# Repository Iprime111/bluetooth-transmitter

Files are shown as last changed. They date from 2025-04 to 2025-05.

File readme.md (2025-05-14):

# Bluetooth Audio Transmitter  
  
  


Портативный Bluetooth-передатчик для беспроводной передачи звука с аналоговых источников (3.5 мм) на наушники или колонки.  
**Цель проекта**: Интеграция проводных аудиоустройств в современные беспроводные экосистемы.

---

## 🚀 Особенности
- **Bluetooth A2DP**: Передача стереозвука с поддержкой кодеков SBC.
- **OLED-дисплей**: SSD1306 (32x64 пикселей) для управления и отображения:
  - Список доступных для подключения устройств.
  - Уровень громкости.
- **Энкодер EC11**: Интуитивное управление (выбор устройств, регулировка громкости).
- **Компактный дизайн**: Корпус 93x61x33 мм, напечатанный на 3D-принтере (PLA).
- **Автономность**: Работа от Li-Po аккумулятора 1050 мАч с зарядкой через USB-C.
- **Открытый исходный код**: Полная документация и файлы для самостоятельной сборки.

---

## 🔧 Технологии и компоненты
### Аппаратная часть
| Компонент | Характеристики | Ссылка на Datasheet |
|---|---|---|
| Микроконтроллер | ESP32-WROOM-32 (Bluetooth 4.2 + Wi-Fi)  | [ESP32-WROOM-32](./docs/esp32-wroom-32_datasheet_en.pdf) |
| АЦП | PCM1808 (24-bit, 96 kHz, SNR 112 dB) | [PCM1808](./docs/pcm1808.pdf)  |
| Драйвер дисплея | SSD1306 (I2C) | [SSD1306](./docs/SSD1306.pdf) |
| Стабилизатор питания | ADP3338 (3.3V) / L78L05 (5V) | [ADP3338](./docs/ADP3338.pdf), [L78L05](./docs/l78l-1.pdf) |
| Модуль заряда | IP2326 (USB-C) | [IP2326](./docs/ip2326.pdf) |
| Энкодер | EC11 | [EC11](./docs/PEC11R.pdf) |

### Программная часть
- **Прошивка**: Написана на C с использованием ESP-IDF v4.4.
- **Библиотеки**:
  - `esp_a2dp` — Реализация Bluetooth A2DP Source (встроенная).
  - `i2s_audio` — Захват аудио с АЦП через I2S (встроенная).
  - `ssd1306` — Управление OLED-дисплеем (написана в рамках проекта).
  - `EC11` — Работа с энкодером (написана в рамках проекта).
- **Инструменты**:
  - `KiCad 7.0` — проектирование схемы и PCB.
  - `Autodesk Inventor` — 3D-моделирование корпуса.
  - `ESP-IDF` — сборка и отладка прошивки.

---

## 📦 Сборка устройства
### 1. Аппаратная часть
#### Схемы и PCB
- [Файлы KiCad](https://github.com/Iprime111/bluetooth-transmitter/tree/master/bluetooth-transmitter-pcb):  
  - Принципиальная схема.  
  - Разводка двухсторонней платы.  
  - Gerber-файлы для заказа на производстве.  

#### 3D-модель корпуса
- [STL и IPT-файлы](https://github.com/Iprime111/bluetooth-transmitter/tree/master/case-design):  
  - Корпус состоит из двух частей: верхняя крышка/корпус с отверстиями для дисплея/энкодера, нижняя — крышка на пазовом соединии.  
  - Рекомендуемые параметры печати: слой 0.2 мм, заполнение 15%.

---

### 2. Программная часть
#### Установка зависимостей
1. Установите [ESP-IDF v5.4](https://docs.espressif.com/projects/esp-idf/en/v5.4.1/esp32/get-started/).
2. Клонируйте репозиторий:
   ```bash
   git clone https://github.com/Iprime111/bluetooth-transmitter.git
   cd bluetooth-transmitter
   ```

#### Компиляция и прошивка
1. Подключите ESP32 через USB.
2. Соберите и загрузите проект:
   ```bash
   idf.py build
   idf.py -p /dev/ttyUSB0 flash
   ```

---

## 🎮 Использование
### Основные функции
1. **Подключение источника звука**:  
   Вставьте кабель 3.5 мм в разъем на корпусе.  
2. **Поиск устройств**:  
   - Включите устройство
   - Нажмите на кнопку энкодера для поиска устройств
   - Поворот энкодера → выбор устройства из списка.  
   - Нажмите энкодер для подключения.
   - При необходимости выберите пункт `RESTART DISCOVER` для повторного сканирования 
3. **Управление громкостью и проигрыванием**:  
   - Выберите пункт `PLAY/STOP` для воспроизведения или остановки аудио
   - Войдите в режим изменения громкости путем выбора соответствующего пункта меню. Поворотом энкодера установите желаемый уровень громкости. Для выхода повторно нажмите кнопку энкодера.  
   - Для отключения нажмите кнопку `BACK`.

---

## 📊 Технические характеристики
| Параметр | Значение |
|---|---|
| Радиус действия | До 15 м (в помещении) |
| Автономность | 8 часов (при 50% громкости)  |
| Задержка передачи | < 200 мс |
| Частотный диапазон | 20 Гц – 20 кГц |

---

## 🔄 Сравнение с аналогами
| Параметр | Наш проект | UGREEN Transmitter | Sennheiser BT-T100 |
|---|---|---|---|
| **Стоимость** | ~$20 (DIY) | ~$40 | ~$100 |
| **Размеры** | 93x61x50 мм | 80x50x20 мм | 100x60x25 мм |
| **Открытость** | Полная | Нет | Нет |
| **Кастомизация** | Да (код + корпус) | Нет | Нет |

---

## 📁 Структура репозитория
```
bluetooth-transmitter/
├── components/           # Исходный код прошивки (ESP-IDF)
│   ├── audio-stream/     # Получение звука с PCM1808
│   ├── bluetooth-lib/    # GAP, AVRC, A2DP и управление подключениями
│   ├── dispatcher/       # Вспомогательные функции для асинхронной работы
│   ├── oled-display/     # Драйвер SSD1306
│   ├── main/             # Конфигурация устройства и пользовательский интерфейс
│   └── encoder/          # Обработка энкодера
├── bluetooth-transmitter-pcb/  # Схемы и PCB (KiCad)
├── case-design/          # 3D-модели корпуса (IPT, STL)
├── docs/                 # Документация
└── README.md             # Этот файл
```

---

## 📜 Лицензия
Проект распространяется под лицензией **MIT**.  
Полный текст доступен в файле [LICENSE](LICENSE).

---

## 👥 Команда
- **Владимир Чурсин**  
  - Разработка ПО, 3D-моделирование.  
  - ✉️ `chursin.vv@phystech.edu`  
  - [GitHub](https://github.com/Amlola)  
- **Максим Тимошкин**  
  - Схемотехника, сборка, тестирование.  
  - ✉️ `timoshkin.ma@phystech.edu`  
  - [GitHub](https://github.com/Iprime111)  

---

## 📸 Фото и демонстрация
**Фотография финальной версии устройства**

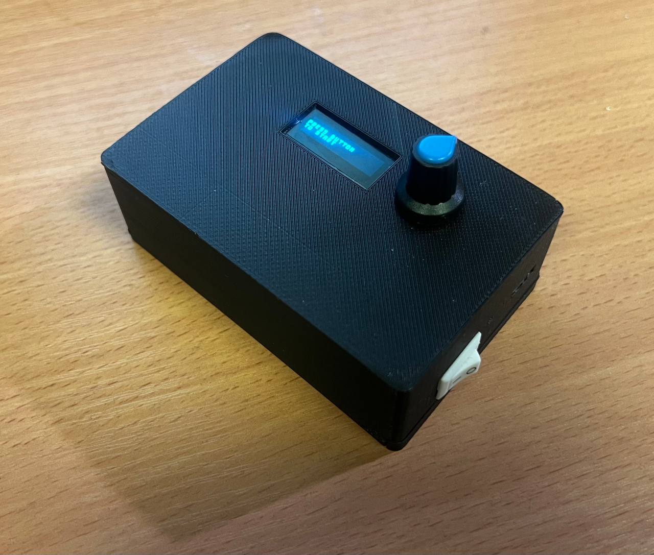
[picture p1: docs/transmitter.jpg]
Bluetooth аудио передатчик


**Фотография прототипа**

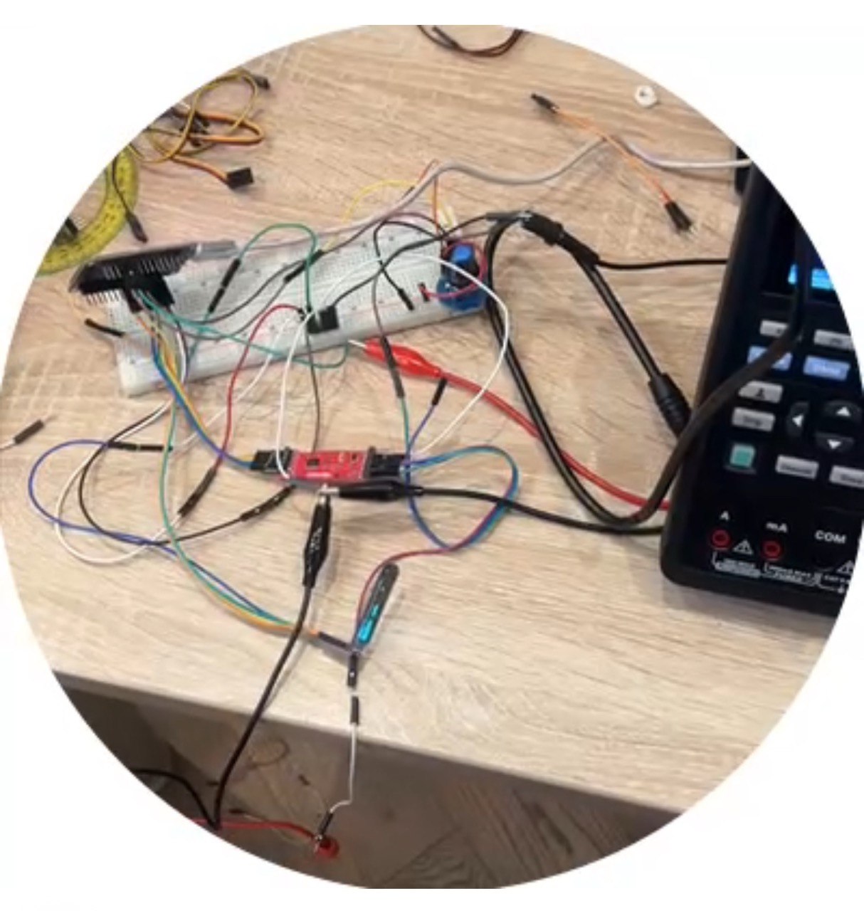
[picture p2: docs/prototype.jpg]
Прототип


**Демонстрация работы**:

<video width="480" height="640" controls>
  <source src="docs/demonstration.mp4" type="video/mp4">
</video>

[Ссылка, если видео не отображается на github](./docs/demonstration.mp4)

---

## 🔮 Будущие улучшения
- Добавление поддержки кодеков aptX.  
- Реализация мультиподключения (2 устройства).  
- Интеграция с мобильным приложением для настройки.  

---

**🔗 Ссылка на проект**: [GitHub](https://github.com/Iprime111/bluetooth-transmitter)

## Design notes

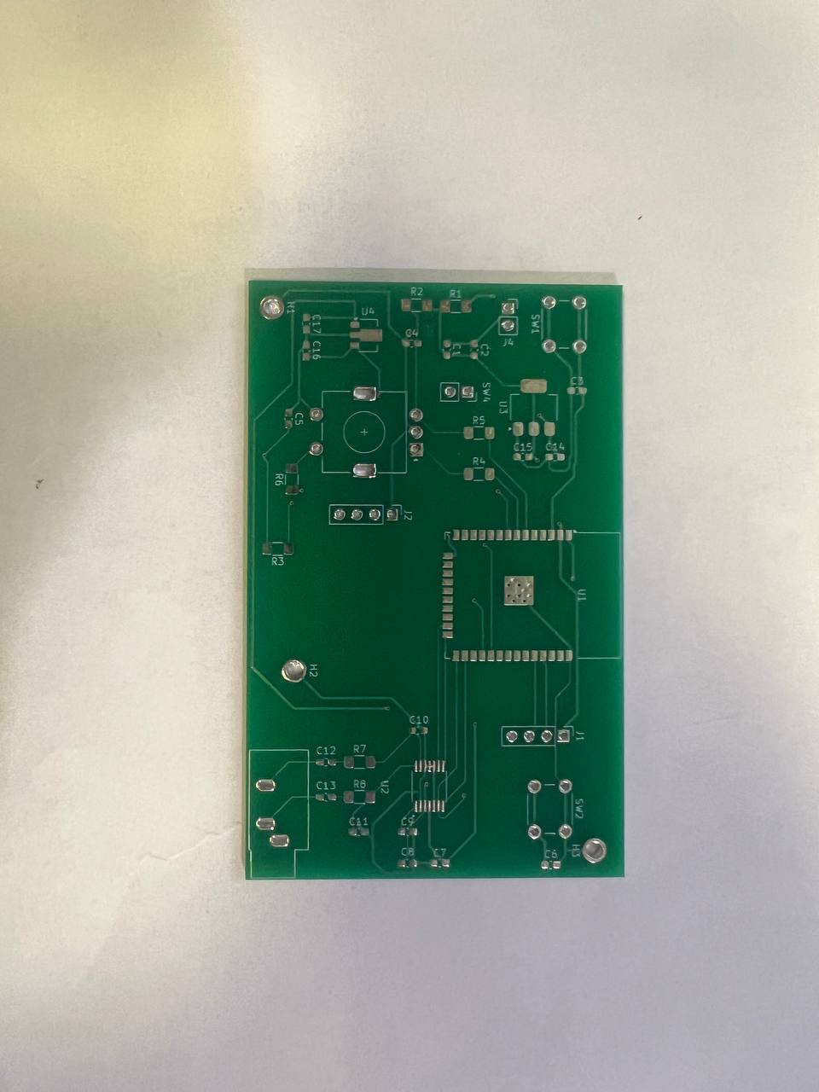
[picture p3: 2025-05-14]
docs/pcb.jpg

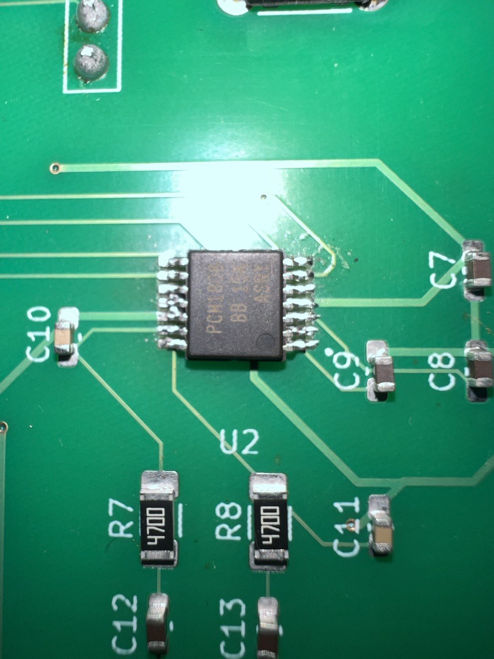
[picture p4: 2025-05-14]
docs/ADC.jpg

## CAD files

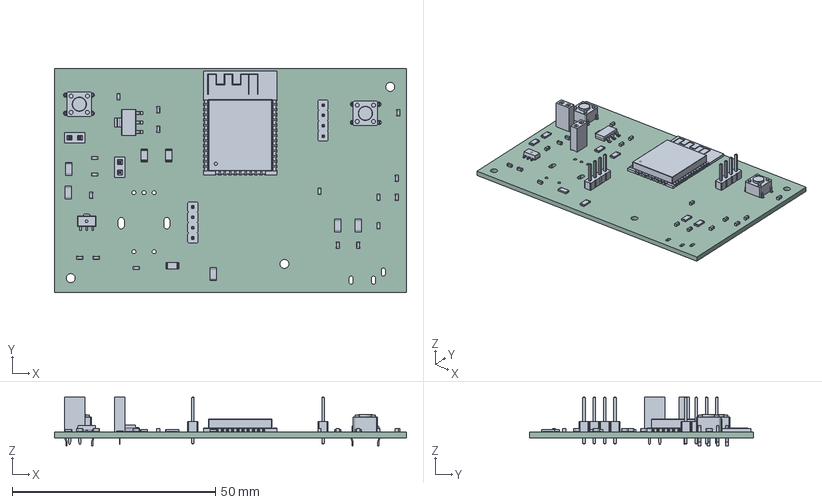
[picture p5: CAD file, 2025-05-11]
bluetooth-transmitter-pcb/bluetooth-transmitter.step
86.5 x 55.0 x 12.0 mm
PinHeader_1x04_P2.54mm_Vertical x 2
C_0603_1608Metric x 17
R_1206_3216Metric x 8
SOT-223
PinSocket_1x02_P2.54mm_Vertical x 2
bluetooth-transmitter 1.22.1
ESP32-WROOM-32
SW_PUSH_6mm_H4.3mm x 2
bluetooth-transmitter_PCB

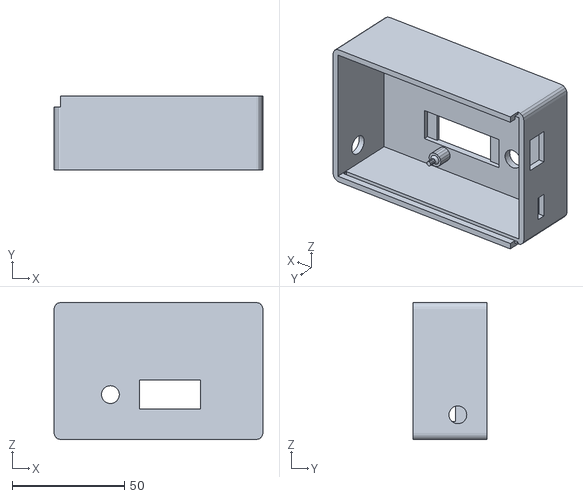
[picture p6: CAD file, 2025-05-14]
case-design/bt-case.stl
93.0 x 33.0 x 61.0

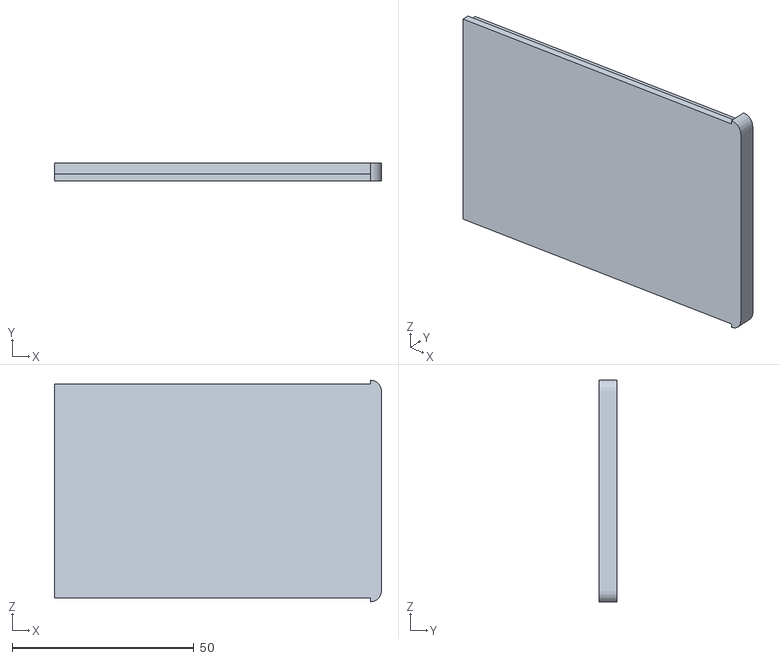
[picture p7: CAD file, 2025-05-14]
case-design/bt-lid.stl
90.0 x 5.00 x 61.0

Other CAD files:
case-design/bt-case.ipt
case-design/bt-lid.ipt

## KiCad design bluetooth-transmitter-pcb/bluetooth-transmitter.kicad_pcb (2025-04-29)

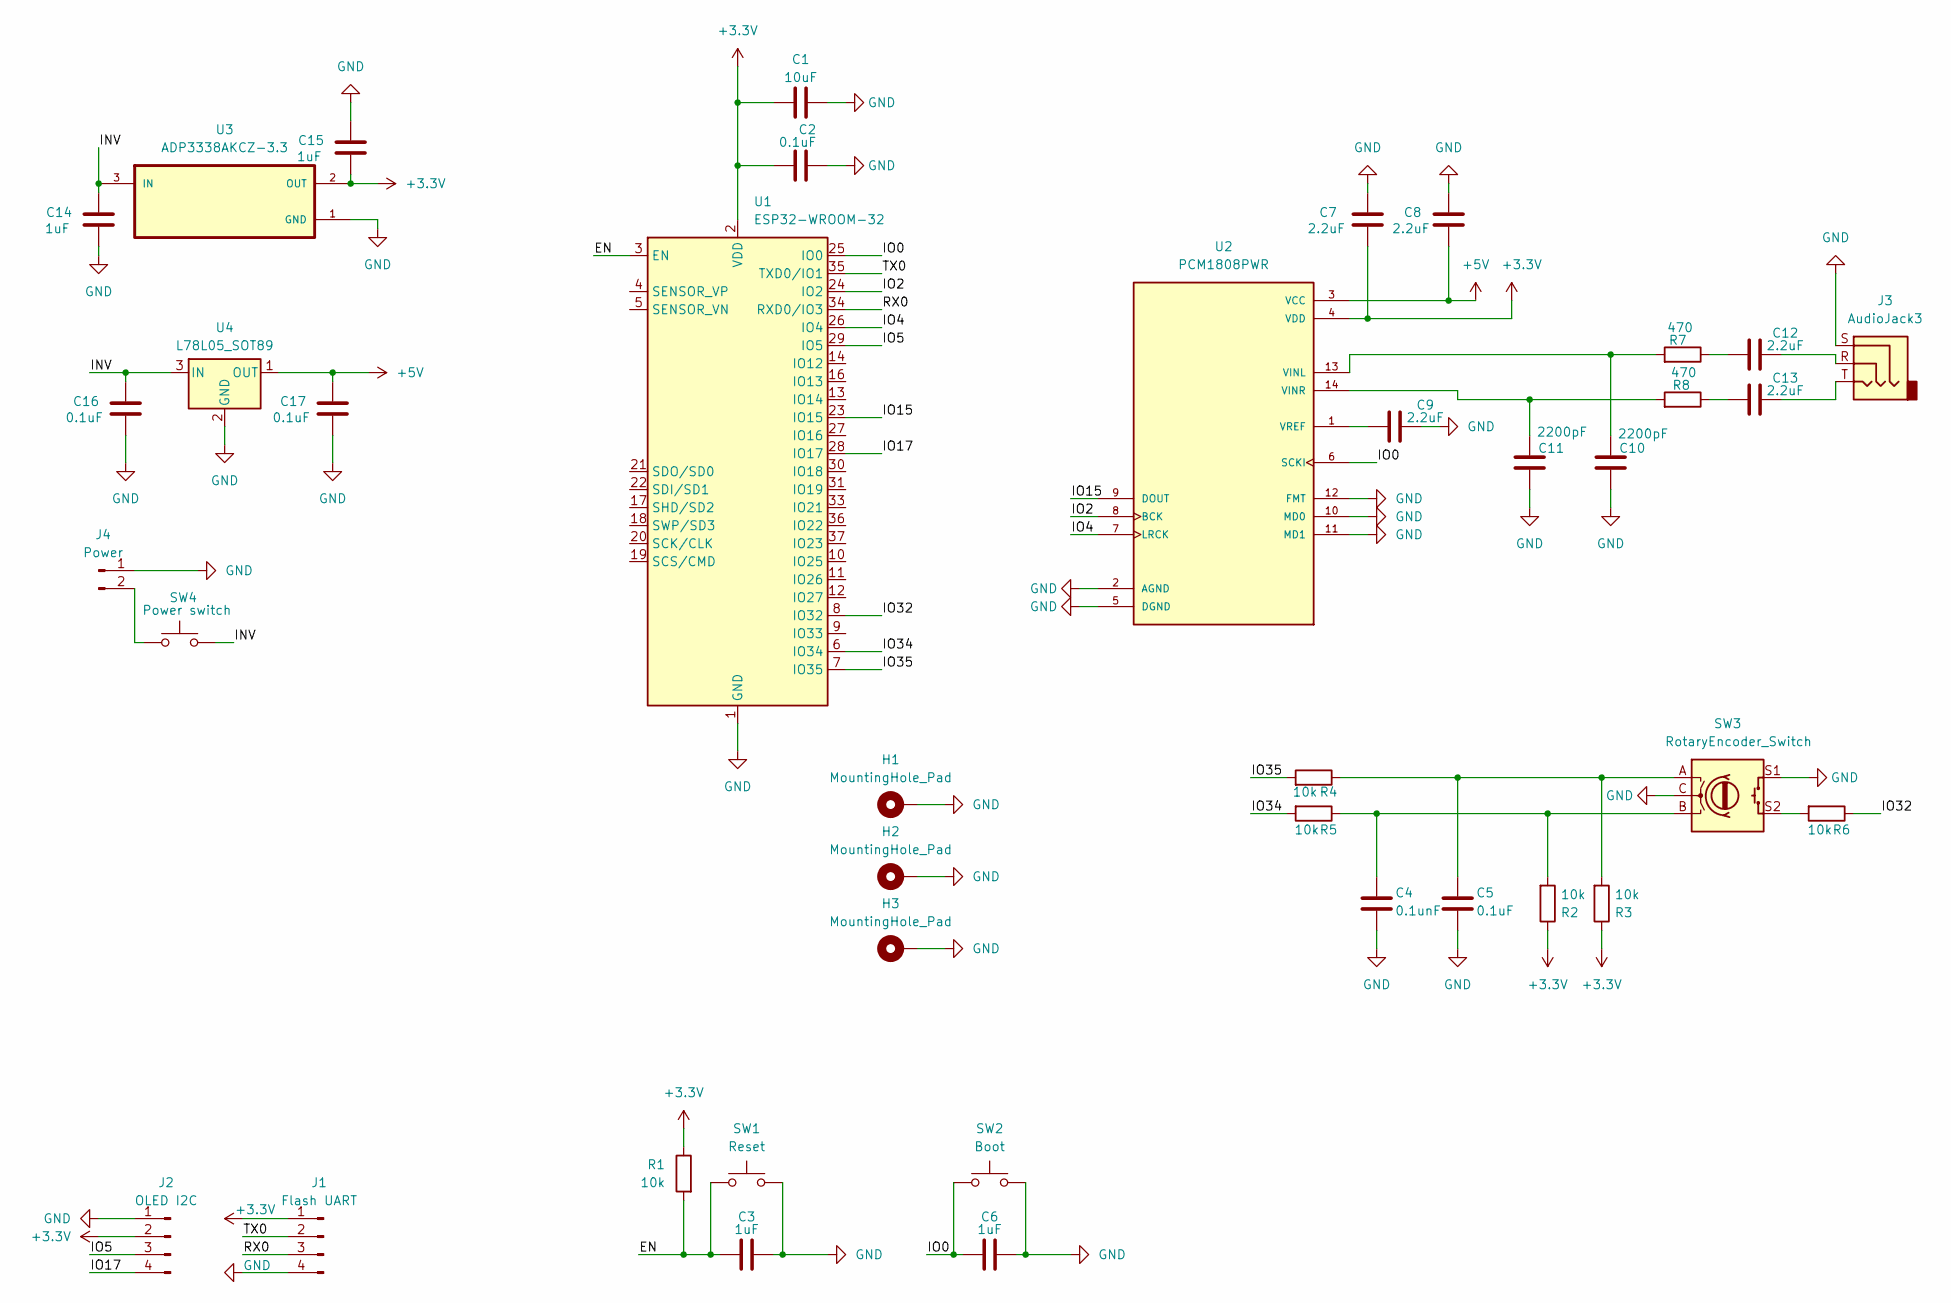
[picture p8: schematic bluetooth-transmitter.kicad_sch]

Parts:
C1: 10uF; C_0603_1608Metric_Pad1.08x0.95mm_HandSolder
C2, C5, C16, C17: 0.1uF; C_0603_1608Metric_Pad1.08x0.95mm_HandSolder
C3, C6, C14, C15: 1uF; C_0603_1608Metric_Pad1.08x0.95mm_HandSolder
C4: 0.1unF; C_0603_1608Metric_Pad1.08x0.95mm_HandSolder
C7, C8, C9, C12, C13: 2.2uF; C_0603_1608Metric_Pad1.08x0.95mm_HandSolder
C10, C11: 2200pF; C_0603_1608Metric_Pad1.08x0.95mm_HandSolder
H1, H2, H3: MountingHole_Pad; MountingHole_2.2mm_M2_ISO7380_Pad_TopOnly
J1: Flash UART; PinHeader_1x04_P2.54mm_Vertical
J2: OLED I2C; PinHeader_1x04_P2.54mm_Vertical
J3: AudioJack3; Jack_3.5mm_CUI_SJ1-3533NG_Horizontal
J4: Power; PinSocket_1x02_P2.54mm_Vertical
R1, R2, R3, R4, R5, R6: 10k; R_1206_3216Metric_Pad1.30x1.75mm_HandSolder
R7, R8: 470; R_1206_3216Metric_Pad1.30x1.75mm_HandSolder
SW1: Reset; SW_PUSH_6mm_H4.3mm
SW2: Boot; SW_PUSH_6mm_H4.3mm
SW3: RotaryEncoder_Switch; RotaryEncoder_Alps_EC11E-Switch_Vertical_H20mm
SW4: Power switch; PinSocket_1x02_P2.54mm_Vertical
U1: ESP32-WROOM-32
U2: PCM1808PWR; SOP65P640X120-14N; PARTREV B
U3: ADP3338AKCZ-3.3; SOT-223-3_TabPin2
U4: L78L05_SOT89; SOT-89-3

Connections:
+3.3V: C1.2, C2.1, C7.2, C15.2, J1.1, J2.2, R1.1, R2.1, R3.1, U1.2 (VDD), U2.4 (VDD), U3.2 (OUT)
+5V: C8.2, C17.1, U2.3 (VCC), U4.1 (OUT)
/EN: C3.2, R1.2, SW1.2, U1.3 (EN)
/INV: C14.1, C16.1, SW4.2, U3.3 (IN), U4.3 (IN)
/IO0: C6.2, SW2.2, U1.25 (IO0), U2.6 (SCKI)
/IO2: U1.24 (IO2), U2.8 (BCK)
/IO4: U1.26 (IO4), U2.7 (LRCK)
/IO5: J2.3, U1.29 (IO5)
/IO15: U1.23 (IO15), U2.9 (DOUT)
/IO17: J2.4, U1.28 (IO17)
/IO32: R6.1, U1.8 (IO32)
/IO34: R5.2, U1.6 (IO34)
/IO35: R4.2, U1.7 (IO35)
/RX0: J1.3, U1.34 (RXD0/IO3)
/TX0: J1.2, U1.35 (TXD0/IO1)
GND: C1.1, C2.2, C3.1, C4.2, C5.2, C6.1, C7.1, C8.1, C9.2, C10.1, C11.1, C14.2, C15.1, C16.2, C17.2, H1.1, H2.1, H3.1, J1.4, J2.1, J3.S, J4.1, SW1.1, SW2.1, SW3.C, SW3.S1, U1.1 (GND), U1.15 (GND), U1.38 (GND), U1.39 (GND), U2.2 (AGND), U2.5 (DGND), U2.10 (MD0), U2.11 (MD1), U2.12 (FMT), U3.1 (GND), U4.2 (GND)
unnamed: C4.1, R2.2, R5.1, SW3.B
unnamed: C5.1, R3.2, R4.1, SW3.A
unnamed: C12.1, R7.1
unnamed: C12.2, J3.R
unnamed: C13.1, R8.1
unnamed: C13.2, J3.T
unnamed: J4.2, SW4.1
unnamed: R6.2, SW3.S2
unnamed: C10.2, R7.2, U2.13 (VINL)
unnamed: C11.2, R8.2, U2.14 (VINR)
unnamed: C9.1, U2.1 (VREF)

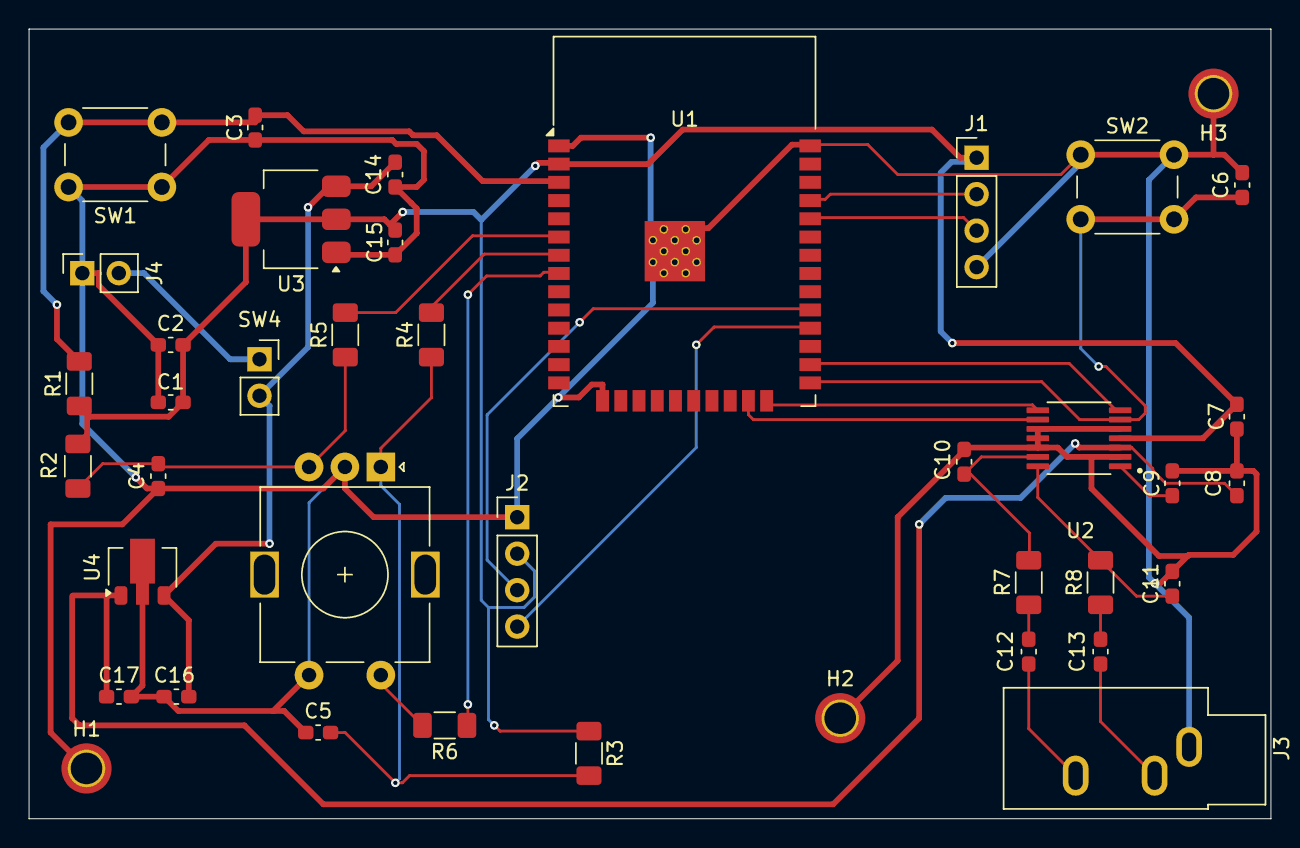
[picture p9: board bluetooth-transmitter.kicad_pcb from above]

Board: 2 copper layers, 86.5 x 55.0 mm, 40 parts (0 on the bottom side), 27 nets.

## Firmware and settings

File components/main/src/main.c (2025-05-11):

#include <math.h>
#include <esp_adc/adc_continuous.h>
#include <soc/soc_caps.h>
#include <esp_log.h>
#include <hal/adc_types.h>
#include <driver/i2c_master.h>
#include <driver/gpio.h>
#include <soc/gpio_num.h>
#include <stdint.h>
#include <string.h>

#include "audio_stream.h"
#include "bt_lib.h"
#include "display.h"
#include "encoder.h"
#include "portmacro.h"
#include "menu.h"
#include "stdbool.h"

#define kMaxFramesRequested (256)
#define kChannelsCount (2)
#define kChannelFrameSize (sizeof(uint32_t))

#define kDisplayAddress (0x3c) // 0x3c for 32-pixels tall displays, 0x3d for others

#define kI2CMasterScl (GPIO_NUM_5)
#define kI2CMasterSda (GPIO_NUM_17)

#define kEncoderAPort (GPIO_NUM_35)
#define kEncoderBPort (GPIO_NUM_34)
#define kEncoderCPort (GPIO_NUM_32)

#define kAudioFrequency (44100)

static uint8_t *audioDataBuffer = NULL;
static InputAudioStream stream = {};

static int32_t audioDataCallback(AudioFrame *data, int32_t len);

void app_main() {
    // Init display
    i2c_master_bus_config_t masterBusConfig = {
        .clk_source = I2C_CLK_SRC_DEFAULT,
        .i2c_port = -1, // Auto selection
        .scl_io_num = kI2CMasterScl,
        .sda_io_num = kI2CMasterSda,
        .glitch_ignore_cnt = 7,
        .flags.enable_internal_pullup = true,
    };

    I2CBus screenBus;
    initI2CBus(&screenBus, &masterBusConfig);

    i2c_device_config_t deviceConfig = {
        .dev_addr_length = I2C_ADDR_BIT_LEN_7,
        .device_address = kDisplayAddress,
        .scl_speed_hz = 100000,
    };

    I2CDevice displayI2C;
    initI2CDevice(&displayI2C, &screenBus, &deviceConfig);

    DisplayDevice display;
    initDisplay(&display, &displayI2C, DISPLAY_128_32);
    setMenuDisplay(&display);

    // Init encoder
    Encoder encoder;
    initEncoder(&encoder, kEncoderAPort, kEncoderBPort, kEncoderCPort);
    setEncoderCallback(&encoder, encoderCallback, NULL);

    // Init I2S
    InputAudioStreamConfig audioStreamConfig = {
        .samplingFrequency = kAudioFrequency,
        .dinPort = GPIO_NUM_15,
        .bclkPort = GPIO_NUM_2,
        .mclkPort = GPIO_NUM_0,
        .wsPort = GPIO_NUM_4,
        .readTimeout = 1000,
    };
    
    audioDataBuffer = calloc(kMaxFramesRequested * kChannelFrameSize * kChannelsCount, sizeof(uint8_t));
    initInputAudioStream(&stream, &audioStreamConfig);

    // Init bluetooth
    BluetoothDeviceCallbacks btCallbacks = {
        .audioDataCallback = audioDataCallback,
        .deviceStateChangedCallback = handleDeviceStateChangedEvent,
        .audioStateChangedCallback = NULL,
        .deviceDiscoveredCallback = handleDeviceDiscoveredEvent,
        .volumeChangedCallback = volumeChangedCallback,
    };

    initBtDevice(&btCallbacks);

    while (true) {
        vTaskDelay(portMAX_DELAY);
    }
    
    free(audioDataBuffer);
    destroyEncoder(&encoder);
    destroyDisplay(&display);
    destroyI2CBus(&screenBus);
}

// 44.1kHz, dual channel (16 bits every frame channel => 32 bits every frame)
static int32_t audioDataCallback(AudioFrame *data, int32_t len) {

    // Every data slot is 32-bytes (for each channel). But we need only 16 of them.
    // Let's take higher 16 bits from every slot
    uint16_t *readData = (uint16_t *)audioDataBuffer;

    readAudioData(&stream, audioDataBuffer, len * 2 * sizeof(uint32_t), NULL);

    for (size_t frameIdx = 0; frameIdx < len; ++frameIdx) {
        data[frameIdx].channel1 = readData[frameIdx * 4 + 1];
        data[frameIdx].channel2 = readData[frameIdx * 4 + 3];

    }

    ESP_LOGI("AAA", "%" PRIu16 "\n", data[0].channel1);

    return len;
}

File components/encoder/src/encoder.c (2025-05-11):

#include <driver/gpio.h>
#include <esp_attr.h>
#include <stdint.h>

#include "encoder.h"
#include "FreeRTOSConfig.h"
#include "esp_err.h"
#include "freertos/idf_additions.h"
#include "freertos/projdefs.h"
#include "hal/gpio_types.h"
#include "portmacro.h"

#define kEncoderQueueSize (40)
#define kTaskStackDepth (4096)
#define kTaskPriority (configMAX_PRIORITIES - 2)
#define kDebounceTimerPeriod (50 / portTICK_PERIOD_MS)

static void IRAM_ATTR isrABPortHandler(void *param);
static void IRAM_ATTR isrSwitchPortHandler(void *param);

static void isrABPortHandler(void *param) {
    Encoder *encoder = param;

    ISRParam queueValue = {
        .port = ENCODER_AB,
        .aState = gpio_get_level(encoder->aPort),
        .bState = gpio_get_level(encoder->bPort),
    };

    xQueueSendFromISR(encoder->queue, &queueValue, 0);
}

static void isrSwitchPortHandler(void *param) {
    Encoder *encoder = param;

    gpio_isr_handler_remove(encoder->switchPort);
    xTimerStart(encoder->switchDebounceTimer, 0);
}

static void switchPortDebounceCheck(TimerHandle_t timer) {
    Encoder *encoder = pvTimerGetTimerID(timer);

    if (gpio_get_level(encoder->switchPort) == 1) {
        ESP_ERROR_CHECK(gpio_isr_handler_add(encoder->switchPort, isrSwitchPortHandler, encoder));
        return;
    }

    ISRParam queueValue = {
        .port = ENCODER_SWITCH,
        .aState = 0,
        .bState = 0,
    };

    ESP_ERROR_CHECK(gpio_isr_handler_add(encoder->switchPort, isrSwitchPortHandler, encoder));
    xQueueSend(encoder->queue, &queueValue, 0);
}

static void monitoringTask(void* param) {
    Encoder *encoder = param;
    ISRParam isrParam;

    while (true) {
        if (xQueueReceive(encoder->queue, &isrParam, portMAX_DELAY) == pdFALSE) {
            continue;
        }

        if (isrParam.port == ENCODER_SWITCH) {
            if (encoder->callback) {
                encoder->callback(ENCODER_SWITCH_PRESSED, encoder->callbackParam);
            }
            continue;
        }

        uint8_t currentState = (isrParam.bState << 1) | isrParam.aState;
        uint8_t lastState = encoder->lastStates & 0x3; // lastStates & 0b00000011

        if (currentState == lastState) {
            continue;
        }

        encoder->lastStates = (encoder->lastStates << 2) | currentState; // Store current state
                                        
        if (!encoder->callback) {
            continue;
        }

        // Check lastStates field documentation
        if (encoder->lastStates == 0x87) { // 0b10000111
            encoder->callback(ENCODER_STEP_CCW, encoder->callbackParam);
        } else if (encoder->lastStates == 0x4b) { // 0b01001011
            encoder->callback(ENCODER_STEP_CW, encoder->callbackParam);
        }
    }
}

void setEncoderCallback(Encoder *encoder, EncoderCallback callback, void *callbackParam) {
    assert(encoder);

    encoder->callback = callback;
    encoder->callbackParam = callbackParam;
}

// ISR service should be started
void initEncoder(Encoder *encoder, gpio_num_t aPort, gpio_num_t bPort, gpio_num_t switchPort) {
    assert(encoder);

    uint64_t aMask = 1ull << aPort;
    uint64_t bMask = 1ull << bPort;
    uint64_t switchMask = 1ull << switchPort;

    encoder->aPort = aPort;
    encoder->bPort = bPort;
    encoder->switchPort = switchPort;

    encoder->callback = NULL;
    encoder->callbackParam = NULL;
    encoder->lastStates = 0;

    encoder->switchDebounceTimer = xTimerCreate("Debounce timer", kDebounceTimerPeriod, pdFALSE, encoder, switchPortDebounceCheck);

    gpio_config_t gpioConfig = {
        .intr_type = GPIO_INTR_ANYEDGE,
        .mode = GPIO_MODE_INPUT,
        .pin_bit_mask = aMask | bMask | switchMask,
        .pull_down_en = 0,
        .pull_up_en = 0,
    };

    ESP_ERROR_CHECK(gpio_config(&gpioConfig));
    ESP_ERROR_CHECK(gpio_pullup_en(switchPort));
    
    gpio_set_intr_type(switchPort, GPIO_INTR_NEGEDGE);

    encoder->queue = xQueueCreate(kEncoderQueueSize, sizeof(ISRParam));
    
    ESP_ERROR_CHECK(gpio_install_isr_service(0));
    ESP_ERROR_CHECK(gpio_isr_handler_add(aPort, isrABPortHandler, encoder));
    ESP_ERROR_CHECK(gpio_isr_handler_add(bPort, isrABPortHandler, encoder));
    ESP_ERROR_CHECK(gpio_isr_handler_add(switchPort, isrSwitchPortHandler, encoder));
    
    xTaskCreate(monitoringTask, "EcoderMonitoringTask", kTaskStackDepth, encoder, kTaskPriority, NULL);
}

void destroyEncoder(Encoder *encoder) {
    if (!encoder) {
        return;
    }

    gpio_isr_handler_remove(encoder->aPort);
    gpio_isr_handler_remove(encoder->bPort);
    gpio_isr_handler_remove(encoder->switchPort);

    encoder->aPort = encoder->bPort = encoder->switchPort = -1;

    if (encoder->monitoringTask) {
        vTaskDelete(encoder->monitoringTask);
        encoder->monitoringTask = NULL;
    }

    if (encoder->queue) {
        vQueueDelete(encoder->queue);
        encoder->queue = NULL;
    }

    encoder->callback = NULL;
    encoder->callbackParam = NULL;
    encoder->lastStates = -1;
}

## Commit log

2025-04-16 Add dispatcher and bt_lib components
    Add first working version of a2dp transmission (white noise)
    [main.c]
2025-04-23 Add encoder lib with button debounce support
    Fix text displaying bug in the display lib
    [bluetooth-transmitter.kicad_sch]
2025-04-24 Add simple device picking menu. Add bt callbacks
2025-04-27 Add volume changing event
    Support correct volume level displaying when controlling from peer.
    Change static const variables to macros to force binary file size
    optimizations.
    [display_construction.c, encoder.c, main.c]
2025-04-29 Change GPIO ports to be in correlation with PCB
2025-04-29 Update PCB to last version
    Add power chain and PCM1808 to schematic. Create PCB from shecmatic.
    Make PCB ready for production.
    [bluetooth-transmitter.kicad_pcb, bluetooth-transmitter.kicad_sch]
2025-05-11 Update ports, enable button pullup
2025-05-11 Update pcb
    [bluetooth-transmitter.step]
2025-05-14 Add 3D models files
    [bt-case.ipt, bt-case.stl, bt-lid.ipt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]
2025-05-14 Rename 3d models folder
    [bt-case.ipt, bt-case.stl, bt-lid.ipt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]
2025-05-14 Remove keys-design folder
    [bt-case.ipt, bt-case.stl, bt-lid.ipt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]

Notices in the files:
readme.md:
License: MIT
